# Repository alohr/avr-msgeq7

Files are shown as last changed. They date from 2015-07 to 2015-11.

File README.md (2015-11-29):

# MSGEQ7 based audio spectrum analyzer

This is a audio spectrum analyzer based on the msgeq7 using an lm3915 as the display driver and an attiny2313 for timing.

## Sandwiched boards in a "sick of beige" case

[Build instructions](kit-r1.md)

<p align="center">
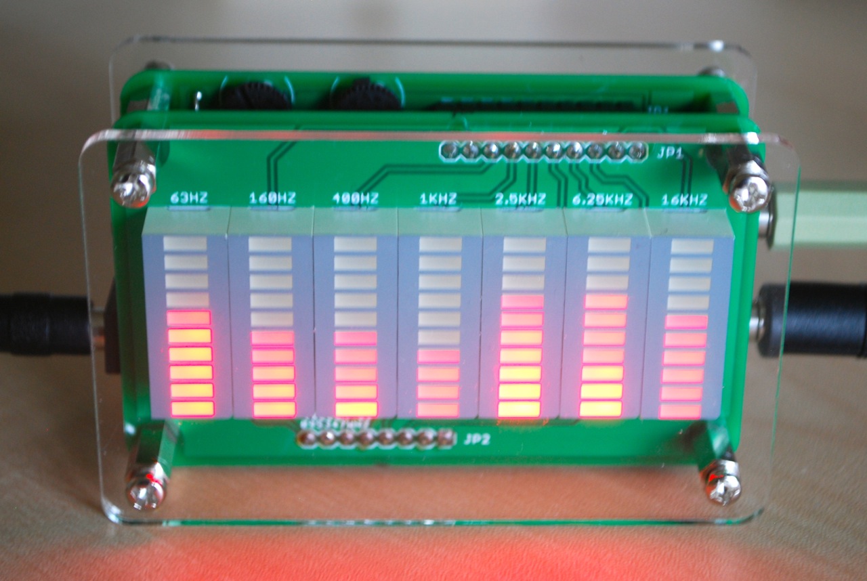
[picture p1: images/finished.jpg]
finished
  
</p>

## Schematic

<p align="center">
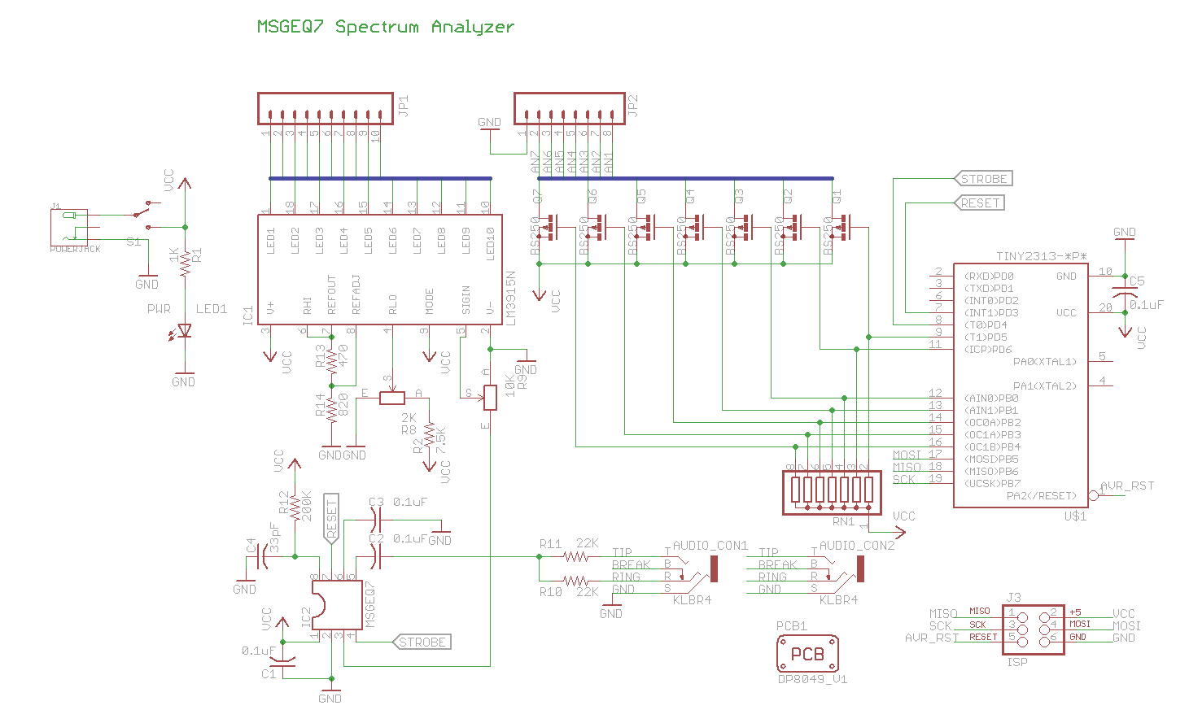
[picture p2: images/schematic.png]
schematic
  
</p>

## Breadboard

<p align="center">
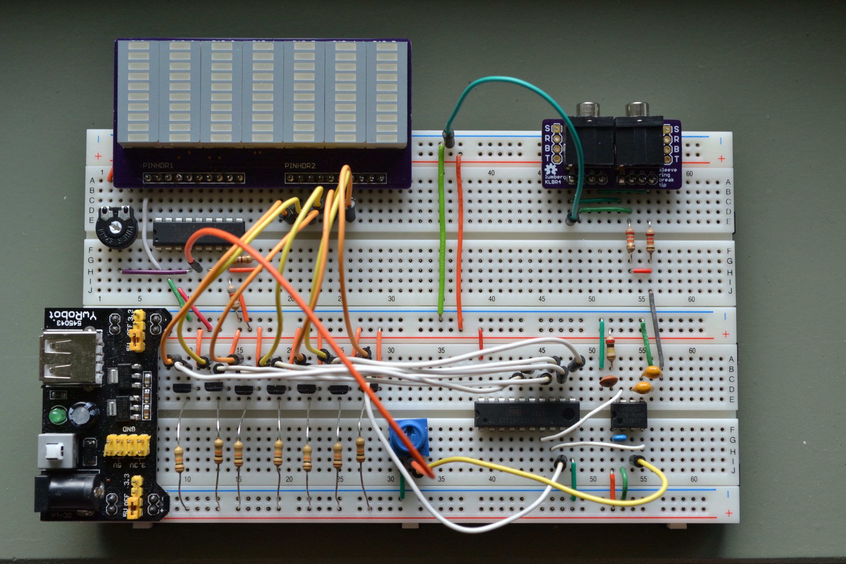
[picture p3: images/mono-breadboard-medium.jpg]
mono on a breadboard
  
</p>

## "Stereo" on a breadboard

Use two msgeq7 and lm3915's to handle the two audio channels independent from each other. One attiny2313 drives both channnels.

<p align="center">
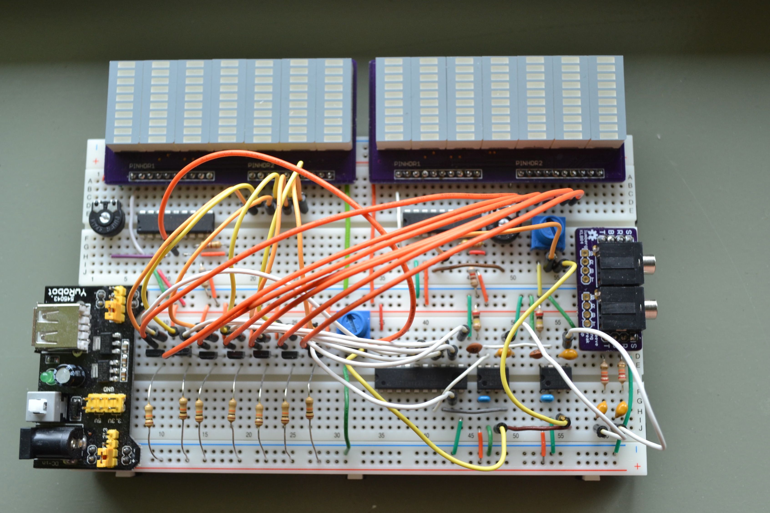
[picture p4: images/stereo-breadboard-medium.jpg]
stereo on a breadboard
  
</p>

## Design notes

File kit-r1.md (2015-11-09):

## Step 1 - Resistors and Capacitors

<p align="center">
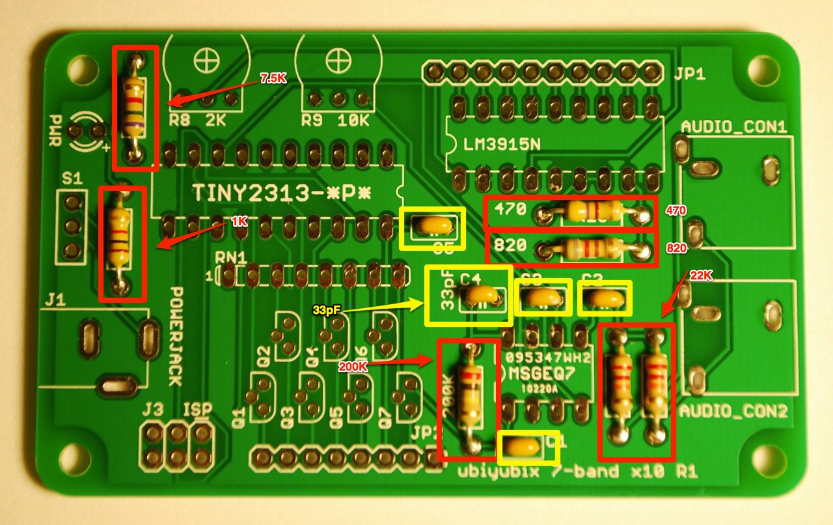
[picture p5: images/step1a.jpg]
step1
  
</p>

## Step 2 - Potentiometers, Resistor Network, Switch

<p align="center">
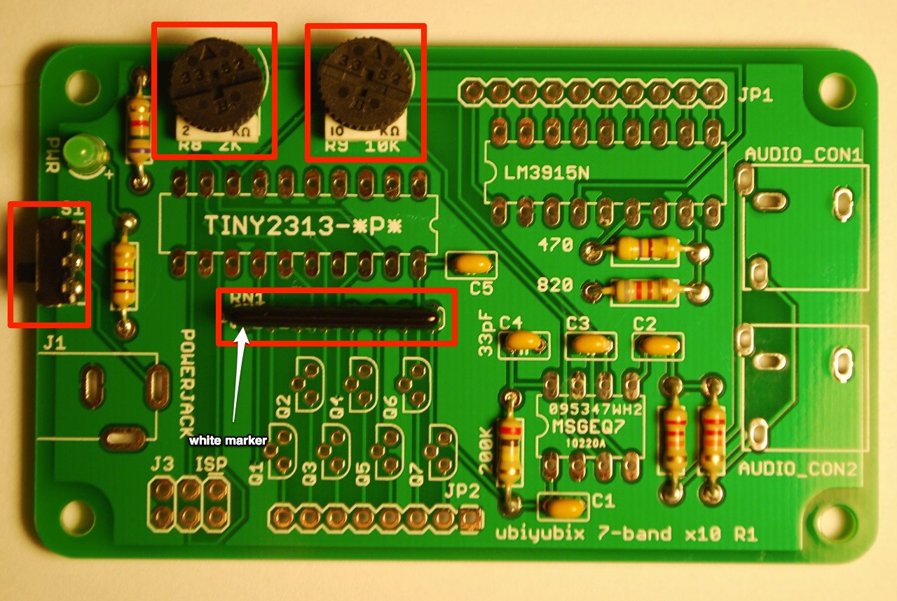
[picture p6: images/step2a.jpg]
step2
  
</p>

## Step 3 - Transistors, Power LED

<p align="center">
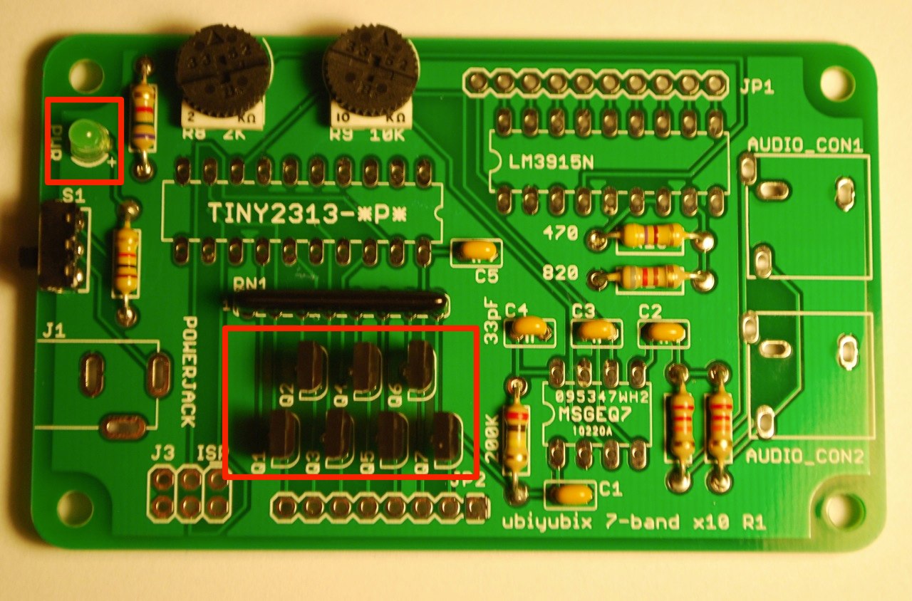
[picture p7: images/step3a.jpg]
step3
  
</p>

## Step 4 - IC Sockets

<p align="center">
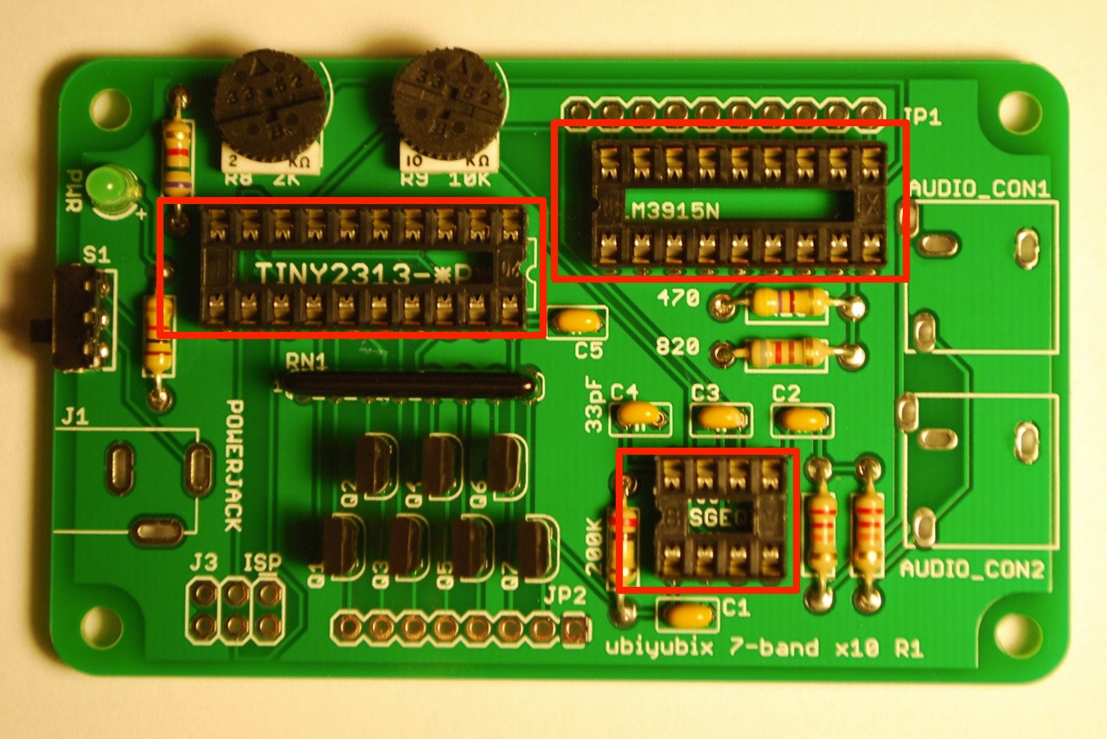
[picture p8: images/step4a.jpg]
step4
  
</p>

## Step 5 - Audio Sockets, Pin Headers

<p align="center">
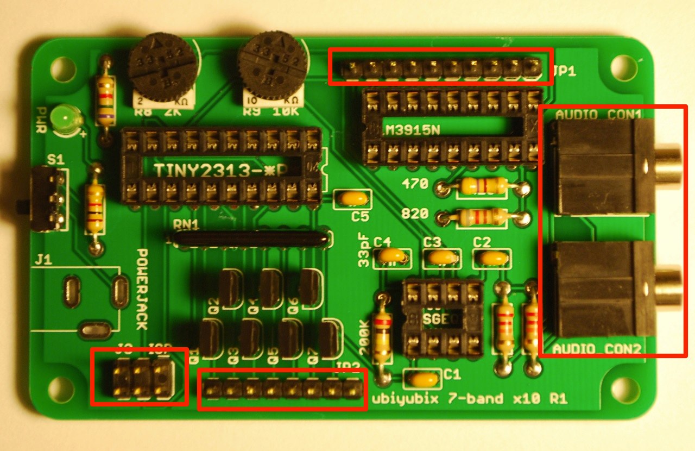
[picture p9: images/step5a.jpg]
step5
  
</p>

## Step 6 - Power Jack

<p align="center">
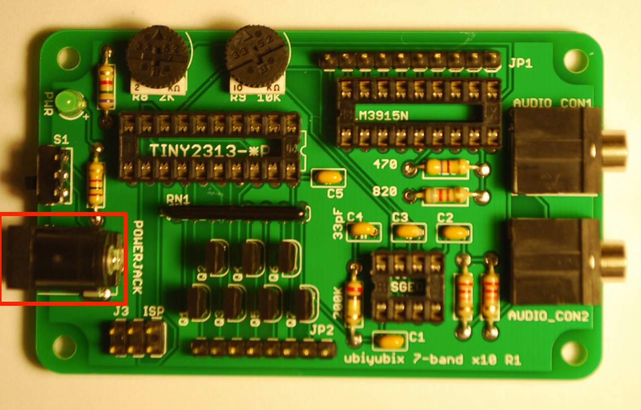
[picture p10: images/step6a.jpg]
step6
  
</p>

## Step 7 - 10 Segment Bar Graph

<p align="center">
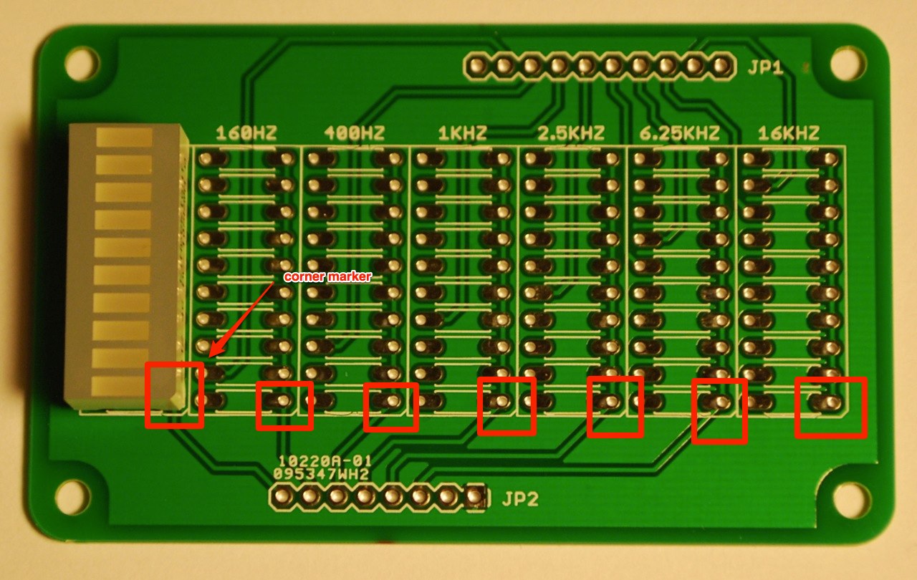
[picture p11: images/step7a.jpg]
step7
  
</p>

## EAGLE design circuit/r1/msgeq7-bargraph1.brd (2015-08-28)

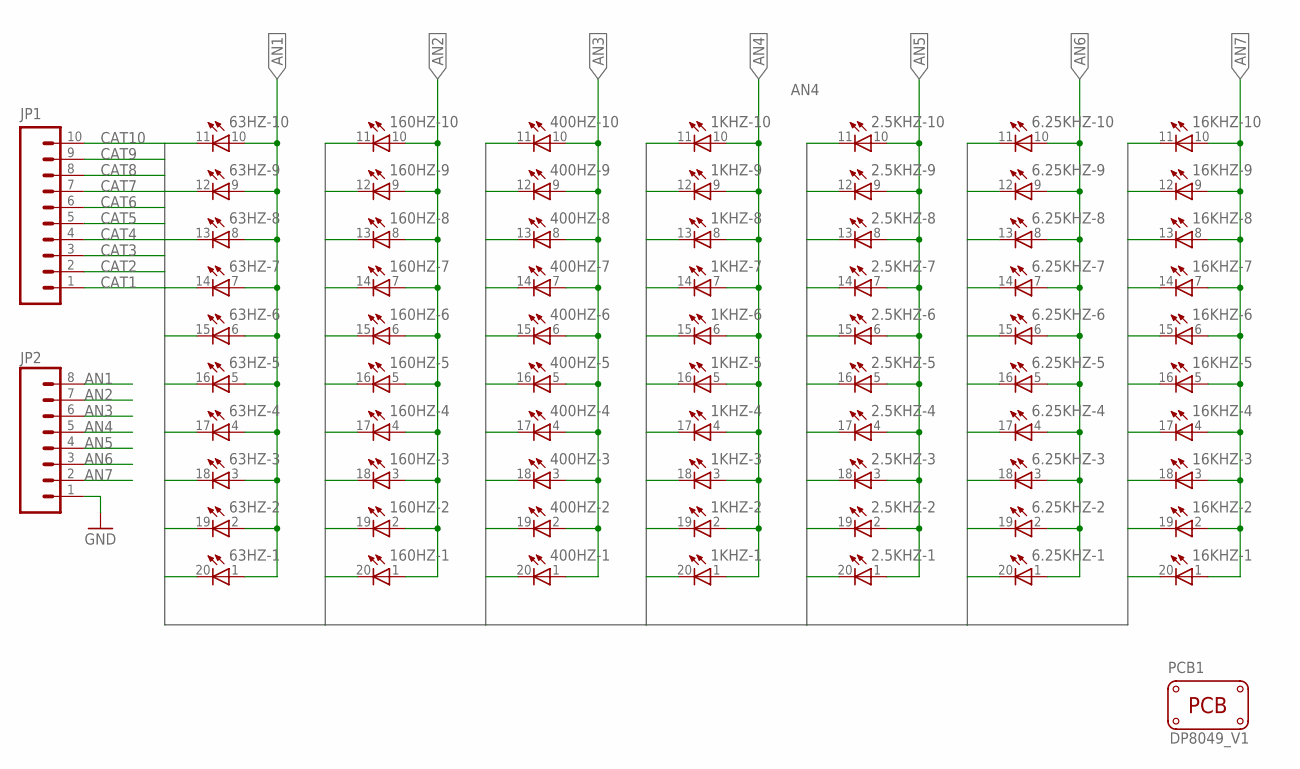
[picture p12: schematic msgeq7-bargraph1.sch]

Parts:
1KHZ, 2.5KHZ, 6.25KHZ, 16KHZ, 63HZ, 160HZ, 400HZ: LB10
JP1: M10"; 1X10
JP2: M081X08; 1X08
PCB1: PCB_DP_RECTANGLE-80X49; DP8049_V1

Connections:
AN1: 63HZ.1 (A), 63HZ.2 (A), 63HZ.3 (A), 63HZ.4 (A), 63HZ.5 (A), 63HZ.6 (A), 63HZ.7 (A), 63HZ.8 (A), 63HZ.9 (A), 63HZ.10 (A), JP2.8
AN2: 160HZ.1 (A), 160HZ.2 (A), 160HZ.3 (A), 160HZ.4 (A), 160HZ.5 (A), 160HZ.6 (A), 160HZ.7 (A), 160HZ.8 (A), 160HZ.9 (A), 160HZ.10 (A), JP2.7
AN3: 400HZ.1 (A), 400HZ.2 (A), 400HZ.3 (A), 400HZ.4 (A), 400HZ.5 (A), 400HZ.6 (A), 400HZ.7 (A), 400HZ.8 (A), 400HZ.9 (A), 400HZ.10 (A), JP2.6
AN4: 1KHZ.1 (A), 1KHZ.2 (A), 1KHZ.3 (A), 1KHZ.4 (A), 1KHZ.5 (A), 1KHZ.6 (A), 1KHZ.7 (A), 1KHZ.8 (A), 1KHZ.9 (A), 1KHZ.10 (A), JP2.5
AN5: 2.5KHZ.1 (A), 2.5KHZ.2 (A), 2.5KHZ.3 (A), 2.5KHZ.4 (A), 2.5KHZ.5 (A), 2.5KHZ.6 (A), 2.5KHZ.7 (A), 2.5KHZ.8 (A), 2.5KHZ.9 (A), 2.5KHZ.10 (A), JP2.4
AN6: 6.25KHZ.1 (A), 6.25KHZ.2 (A), 6.25KHZ.3 (A), 6.25KHZ.4 (A), 6.25KHZ.5 (A), 6.25KHZ.6 (A), 6.25KHZ.7 (A), 6.25KHZ.8 (A), 6.25KHZ.9 (A), 6.25KHZ.10 (A), JP2.3
AN7: 16KHZ.1 (A), 16KHZ.2 (A), 16KHZ.3 (A), 16KHZ.4 (A), 16KHZ.5 (A), 16KHZ.6 (A), 16KHZ.7 (A), 16KHZ.8 (A), 16KHZ.9 (A), 16KHZ.10 (A), JP2.2
CAT1: 1KHZ.20 (C), 2.5KHZ.20 (C), 6.25KHZ.20 (C), 16KHZ.20 (C), 63HZ.20 (C), 160HZ.20 (C), 400HZ.20 (C), JP1.1
CAT2: 1KHZ.19 (C), 2.5KHZ.19 (C), 6.25KHZ.19 (C), 16KHZ.19 (C), 63HZ.19 (C), 160HZ.19 (C), 400HZ.19 (C), JP1.2
CAT3: 1KHZ.18 (C), 2.5KHZ.18 (C), 6.25KHZ.18 (C), 16KHZ.18 (C), 63HZ.18 (C), 160HZ.18 (C), 400HZ.18 (C), JP1.3
CAT4: 1KHZ.17 (C), 2.5KHZ.17 (C), 6.25KHZ.17 (C), 16KHZ.17 (C), 63HZ.17 (C), 160HZ.17 (C), 400HZ.17 (C), JP1.4
CAT5: 1KHZ.16 (C), 2.5KHZ.16 (C), 6.25KHZ.16 (C), 16KHZ.16 (C), 63HZ.16 (C), 160HZ.16 (C), 400HZ.16 (C), JP1.5
CAT6: 1KHZ.15 (C), 2.5KHZ.15 (C), 6.25KHZ.15 (C), 16KHZ.15 (C), 63HZ.15 (C), 160HZ.15 (C), 400HZ.15 (C), JP1.6
CAT7: 1KHZ.14 (C), 2.5KHZ.14 (C), 6.25KHZ.14 (C), 16KHZ.14 (C), 63HZ.14 (C), 160HZ.14 (C), 400HZ.14 (C), JP1.7
CAT8: 1KHZ.13 (C), 2.5KHZ.13 (C), 6.25KHZ.13 (C), 16KHZ.13 (C), 63HZ.13 (C), 160HZ.13 (C), 400HZ.13 (C), JP1.8
CAT9: 1KHZ.12 (C), 2.5KHZ.12 (C), 6.25KHZ.12 (C), 16KHZ.12 (C), 63HZ.12 (C), 160HZ.12 (C), 400HZ.12 (C), JP1.9
CAT10: 1KHZ.11 (C), 2.5KHZ.11 (C), 6.25KHZ.11 (C), 16KHZ.11 (C), 63HZ.11 (C), 160HZ.11 (C), 400HZ.11 (C), JP1.10
GND: JP2.1

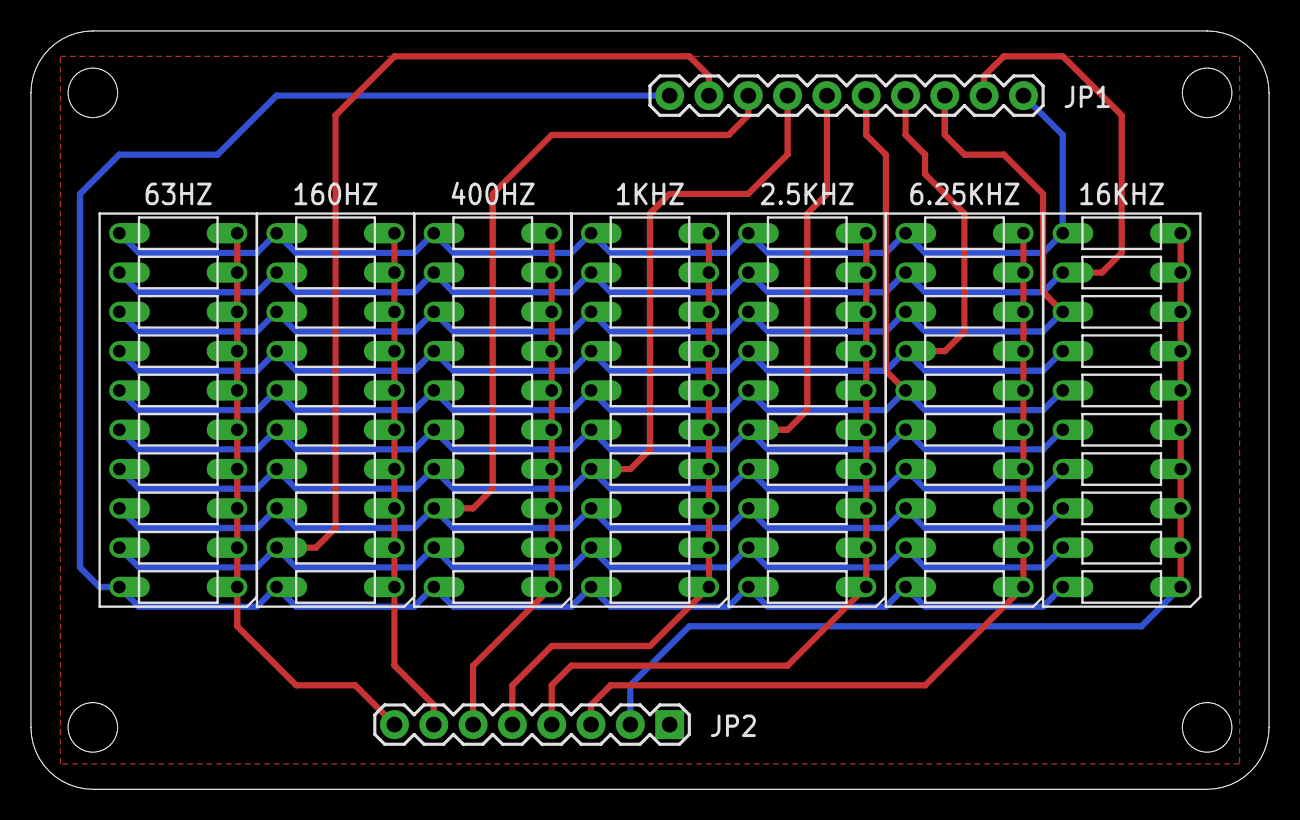
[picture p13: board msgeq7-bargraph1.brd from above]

Board: 2 copper layers, 80.0 x 49.0 mm, 10 parts (0 on the bottom side), 17 nets.

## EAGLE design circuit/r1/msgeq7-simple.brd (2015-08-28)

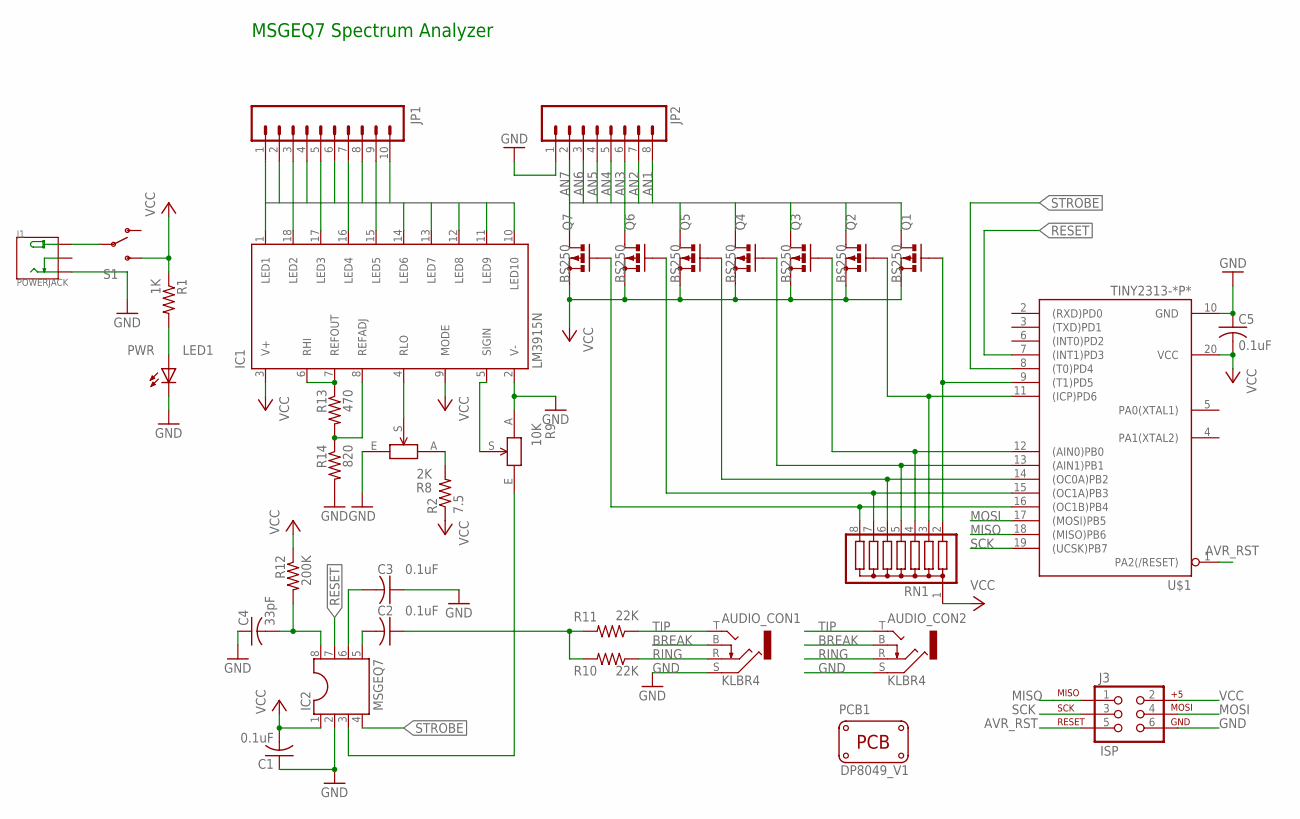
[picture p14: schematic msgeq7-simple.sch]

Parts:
AUDIO_CON1, AUDIO_CON2: KLBR4
C1, C2, C3, C5: 0.1uF; C025-025X050
C4: 33pF; C025-025X050
IC1: LM3915N; DIL18
IC2: MSGEQ7; DIL08
J1: POWERJACK; PW-3P-2.1
J3: ISP; 2X3
JP1: M10"; 1X10
JP2: M081X08; 1X08
LED1: PWR; LED3MM
PCB1: PCB_DP_RECTANGLE-80X49; DP8049_V1
Q1, Q2, Q3, Q4, Q5, Q6, Q7: BS250; TO92-E-LINE
R1: 1K; AXIAL-0.4
R2: 7.5; AXIAL-0.4
R8: 2K; 3352T
R9: 10K; 3352T
R10, R11: 22K; AXIAL-0.4
R12: 200K; AXIAL-0.4
R13: 470; AXIAL-0.4
R14: 820; AXIAL-0.4
RN1: G07R; SIL8
S1: SWITCH-SPDTPTH; SWITCH-SPDT
U$1: TINY2313-*P*; DIL20

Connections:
AN1: JP2.8, Q1.D
AN2: JP2.7, Q2.D
AN3: JP2.6, Q3.D
AN4: JP2.5, Q4.D
AN5: JP2.4, Q5.D
AN6: JP2.3, Q6.D
AN7: JP2.2, Q7.D
AVR_RST: J3.5, U$1.1 (PA2(/RESET))
BREAK: AUDIO_CON1.B, AUDIO_CON2.B
CAT1: IC1.1 (LED1), JP1.1
CAT2: IC1.18 (LED2), JP1.2
CAT3: IC1.17 (LED3), JP1.3
CAT4: IC1.16 (LED4), JP1.4
CAT5: IC1.15 (LED5), JP1.5
CAT6: IC1.14 (LED6), JP1.6
CAT7: IC1.13 (LED7), JP1.7
CAT8: IC1.12 (LED8), JP1.8
CAT9: IC1.11 (LED9), JP1.9
CAT10: IC1.10 (LED10), JP1.10
GND: AUDIO_CON1.S, AUDIO_CON2.S, C1.1, C3.1, C4.1, C5.1, IC1.2 (V-), IC2.2, J1.-1 (-), J3.6, JP2.1, LED1.K (C), R8.E, R9.A, R14.P$2 (2), U$1.10 (GND)
MISO: J3.1, U$1.18 ((MISO)PB6)
MOSI: J3.4, U$1.17 ((MOSI)PB5)
unnamed: Q7.G, RN1.8, U$1.16 ((OC1B)PB4)
unnamed: Q6.G, RN1.7, U$1.15 ((OC1A)PB3)
unnamed: Q5.G, RN1.6, U$1.14 ((OC0A)PB2)
unnamed: Q4.G, RN1.5, U$1.13 ((AIN1)PB1)
unnamed: Q3.G, RN1.4, U$1.12 ((AIN0)PB0)
unnamed: Q2.G, RN1.3, U$1.11 ((ICP)PD6)
unnamed: Q1.G, RN1.2, U$1.9 ((T1)PD5)
unnamed: IC1.4 (RLO), R8.S
unnamed: IC1.5 (SIGIN), R9.S
unnamed: C2.2, IC2.5
unnamed: IC2.3, R9.E
unnamed: J1.+, S1.2
unnamed: C2.1, R10.P$2 (2), R11.P$2 (2)
unnamed: C3.2, IC2.6
unnamed: C4.2, IC2.8, R12.P$2 (2)
unnamed: IC1.6 (RHI), IC1.7 (REFOUT), R13.P$1 (1)
unnamed: IC1.8 (REFADJ), R13.P$2 (2), R14.P$1 (1)
unnamed: LED1.A, R1.P$2 (2)
unnamed: R2.P$2 (2), R8.A
RESET: IC2.7, U$1.7 ((INT1)PD3)
RING: AUDIO_CON1.R, AUDIO_CON2.R, R10.P$1 (1)
SCK: J3.3, U$1.19 ((UCSK)PB7)
STROBE: IC2.4, U$1.8 ((T0)PD4)
TIP: AUDIO_CON1.T, AUDIO_CON2.T, R11.P$1 (1)
VCC: C1.2, C5.2, IC1.3 (V+), IC1.9 (MODE), IC2.1, J3.2, Q1.S, Q2.S, Q3.S, Q4.S, Q5.S, Q6.S, Q7.S, R1.P$1 (1), R2.P$1 (1), R12.P$1 (1), RN1.1, S1.3 (S), U$1.20 (VCC)

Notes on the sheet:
MSGEQ7 Spectrum Analyzer

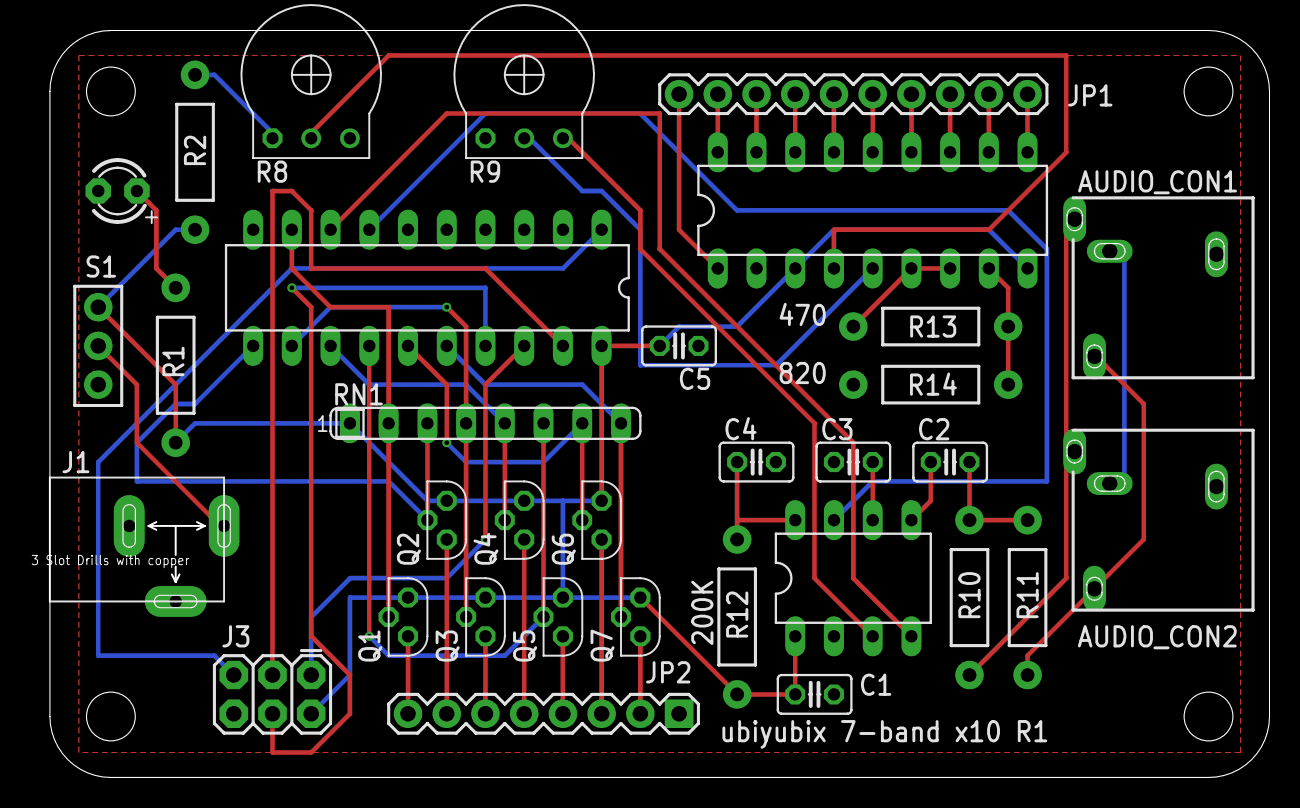
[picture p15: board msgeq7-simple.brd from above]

Board: 2 copper layers, 80.0 x 49.0 mm, 34 parts (0 on the bottom side), 47 nets.

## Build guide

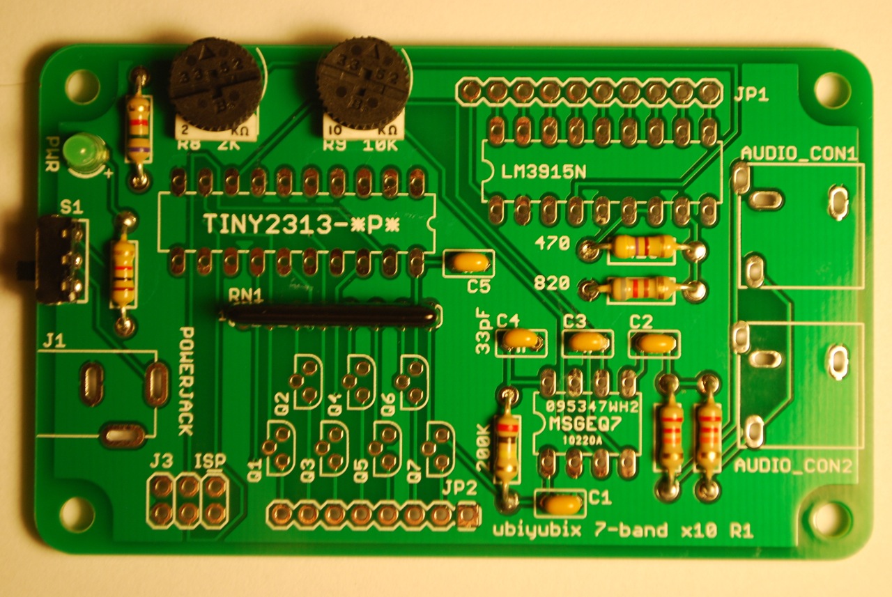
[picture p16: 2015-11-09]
images/step2.jpg

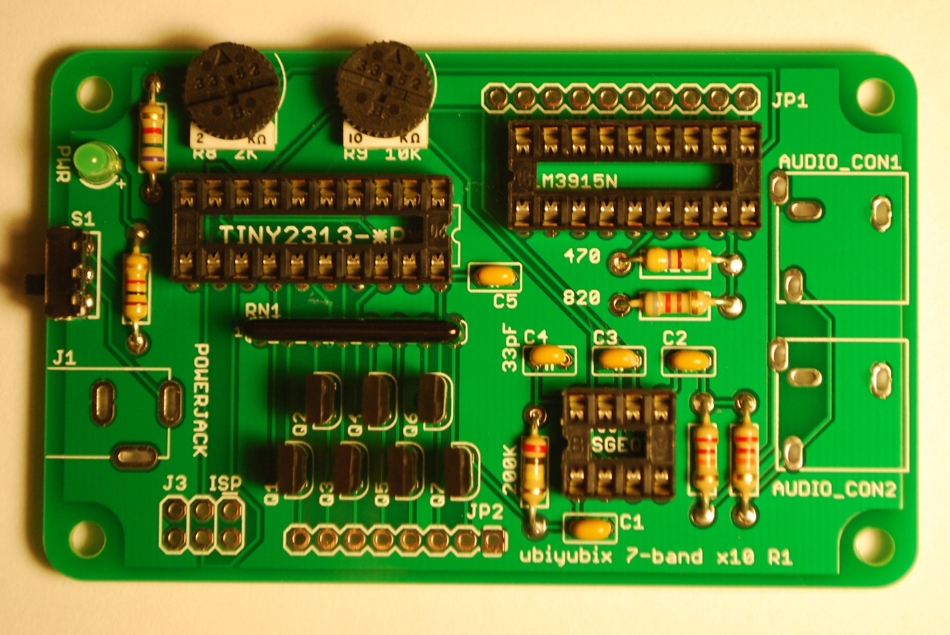
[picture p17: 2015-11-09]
images/step4.jpg

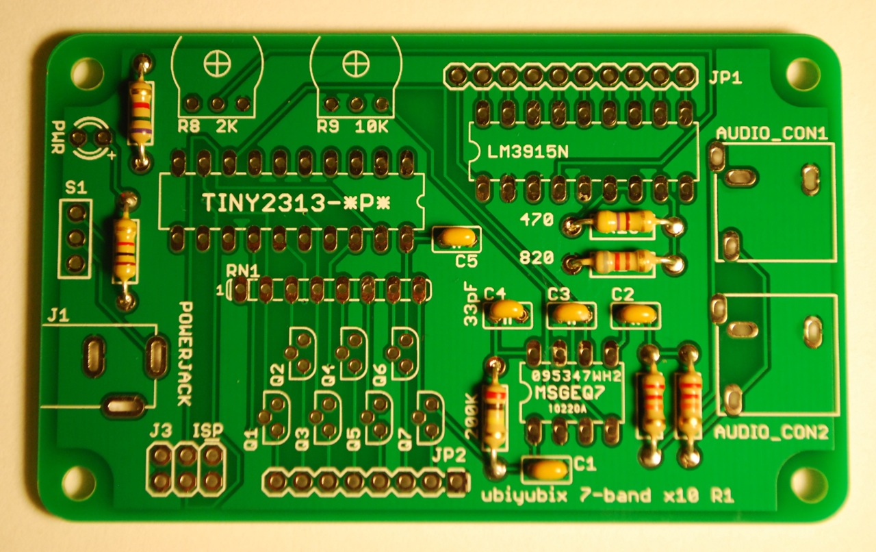
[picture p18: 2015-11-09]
images/step1.jpg

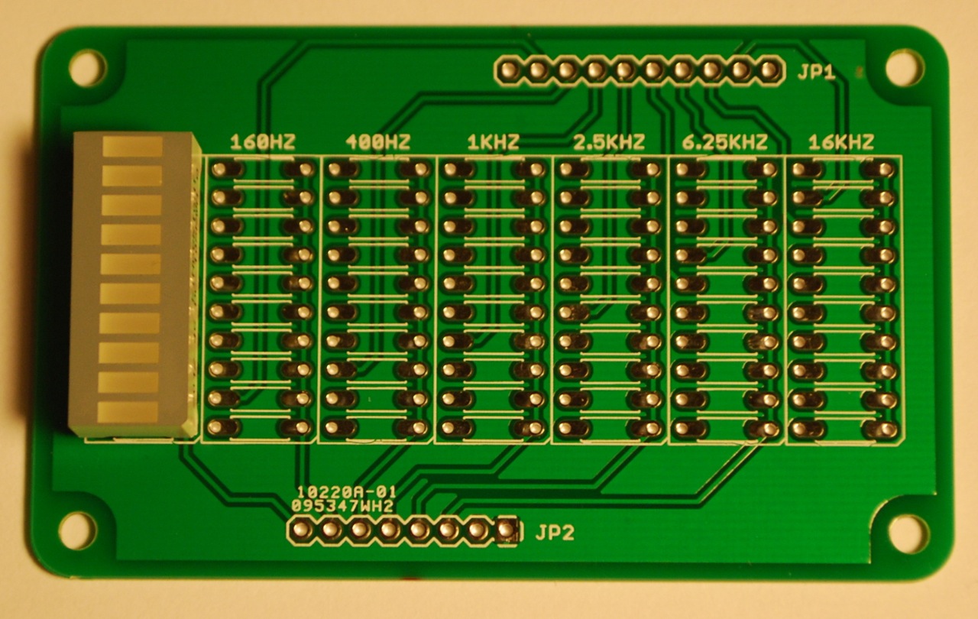
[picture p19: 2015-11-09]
images/step7.jpg

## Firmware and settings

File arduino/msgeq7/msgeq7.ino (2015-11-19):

// atmega328p
//                       +-\/-+
//                 PC6  1|    |28  PC5 (AI 5)
//           (D 0) PD0  2|    |27  PC4 (AI 4)
//           (D 1) PD1  3|    |26  PC3 (AI 3)
//           (D 2) PD2  4|    |25  PC2 (AI 2)
//      PWM+ (D 3) PD3  5|    |24  PC1 (AI 1)
//           (D 4) PD4  6|    |23  PC0 (AI 0)
//                 VCC  7|    |22  GND
//                 GND  8|    |21  AREF
//                 PB6  9|    |20  AVCC
//                 PB7 10|    |19  PB5 (D 13)
//      PWM+ (D 5) PD5 11|    |18  PB4 (D 12)
//      PWM+ (D 6) PD6 12|    |17  PB3 (D 11) PWM
//           (D 7) PD7 13|    |16  PB2 (D 10) PWM
//           (D 8) PB0 14|    |15  PB1 (D 9) PWM
//                       +----+
//

// attiny2313
//                       +-\/-+
//            RESET PA2 1|    |20 VCC
//              RxD PD0 2|    |19 PB7 UCSK
//              TxD PD1 3|    |18 PB6 MISO
//            XTAL2 PA1 4|    |17 PB5 MOSI
//            XTAL1 PA0 5|    |16 PB4 OC1B (band 1)
//             INT0 PD2 6|    |15 PB3 OC1A (band 2)
// (reset)     INT1 PD3 7|    |14 PB2 OC0A (band 3)
// (strobe)      T0 PD4 8|    |13 PB1 AIN1 (band 4)
// (band 6) OC0B T1 PD5 9|    |12 PB0 AIN0 (band 5)
//                 GND 10|    |11 PD6 ICP  (band 6)
//                       +----+

enum {
    tr  = 10,    // reset pulse width (microseconds)
    trs = 80,    // reset-to-strobe (microseconds)
    to  = 40,    // output settling time (microseconds)
    tss = 1800,  // strobe-to-strobe (microseconds; much, much higher than the mininum)
};

struct signal_pins {
    volatile uint8_t *ddr;
    volatile uint8_t *port;
    uint8_t bit;
};

#if defined(__AVR_ATmega328P__)
struct signal_pins signal_pins[] = {
    { &DDRD, &PORTD, PD7 }, // D7  - band 1
    { &DDRB, &PORTB, PB0 }, // D8  - band 2
    { &DDRB, &PORTB, PB1 }, // D9  - band 3
    { &DDRB, &PORTB, PB2 }, // D10 - band 4
    { &DDRB, &PORTB, PB3 }, // D11 - band 5
    { &DDRB, &PORTB, PB4 }, // D12 - band 6
    { &DDRB, &PORTB, PB5 }, // D13 - band 7
};
struct signal_pins control_pins[] = {
    { &DDRD, &PORTD, PD5 }, // reset
    { &DDRD, &PORTD, PD4 }, // strobe
};

#elif defined(__AVR_ATtiny2313__)  \
   || defined(__AVR_ATtiny2313A__) \
   || defined(__AVR_ATtiny4313__)

struct signal_pins signal_pins[] = {
    { &DDRD, &PORTD, PD5 }, // band 1
    { &DDRD, &PORTD, PD6 }, // band 2
    { &DDRB, &PORTB, PB0 }, // band 3
    { &DDRB, &PORTB, PB1 }, // band 4
    { &DDRB, &PORTB, PB2 }, // band 5
    { &DDRB, &PORTB, PB3 }, // band 6
    { &DDRB, &PORTB, PB4 }, // band 7
};
struct signal_pins control_pins[] = {
    { &DDRD, &PORTD, PD3 }, // reset
    { &DDRD, &PORTD, PD4 }, // strobe
};
#endif

struct signal_pins *reset = &control_pins[0];
struct signal_pins *strobe = &control_pins[1];

#define ARRARY_SIZE(a) (sizeof(a) / sizeof((a)[0]))

inline void setbit(volatile uint8_t *port, uint8_t bit)
{
    *port |= _BV(bit);
}

inline void clearbit(volatile uint8_t *port, uint8_t bit)
{
    *port &= ~_BV(bit);
}

void setup()
{
    // initialize reset and strobe
    setbit(reset->ddr, reset->bit);
    setbit(strobe->ddr, strobe->bit);

    // reset low, strobe high
    clearbit(reset->port, reset->bit);
    setbit(strobe->port, strobe->bit);

    // signalling ports
    for (int i = 0; i < ARRARY_SIZE(signal_pins); i++) {
        const struct signal_pins *s = &signal_pins[i];
        setbit(s->ddr, s->bit);
        setbit(s->port, s->bit);
    }
}

void msgeq7_reset(void)
{
    setbit(reset->port, reset->bit);
    _delay_us(tr);

    clearbit(reset->port, reset->bit);
    _delay_us(trs);
}

void msgeq7_strobe(void)
{
    for (int i = 0; i < ARRARY_SIZE(signal_pins); i++) {
        const struct signal_pins *s = &signal_pins[i];

        clearbit(strobe->port, strobe->bit);
        _delay_us(to);

        clearbit(s->port, s->bit);
        _delay_us(tss / 2 - to);

        setbit(strobe->port, strobe->bit);
        _delay_us(tss / 2);

        setbit(s->port, s->bit);
    }
}

void loop()
{
    msgeq7_reset();
    msgeq7_strobe();
}

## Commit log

2015-06-28 added simple circuit
    [msgeq7-simple.brd, msgeq7-simple.sch]
2015-06-28 added lm3915 current calculator
2015-07-12 center schematic
2015-07-12 fixed location of R12
    [msgeq7-simple.brd, msgeq7-simple.sch]
2015-07-12 new schematic image
2015-08-28 ordered r1 of circuit boards from seeed
    [msgeq7-bargraph1.GBL, msgeq7-bargraph1.GBO, msgeq7-bargraph1.GBP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]
2015-11-17 added fuse settings for different devices
2015-11-19 added arduino
2015-11-29 fixed link to schematic
2015-11-29 fixed link to schematic (next try)

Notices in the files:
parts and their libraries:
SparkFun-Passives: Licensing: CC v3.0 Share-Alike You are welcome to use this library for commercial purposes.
